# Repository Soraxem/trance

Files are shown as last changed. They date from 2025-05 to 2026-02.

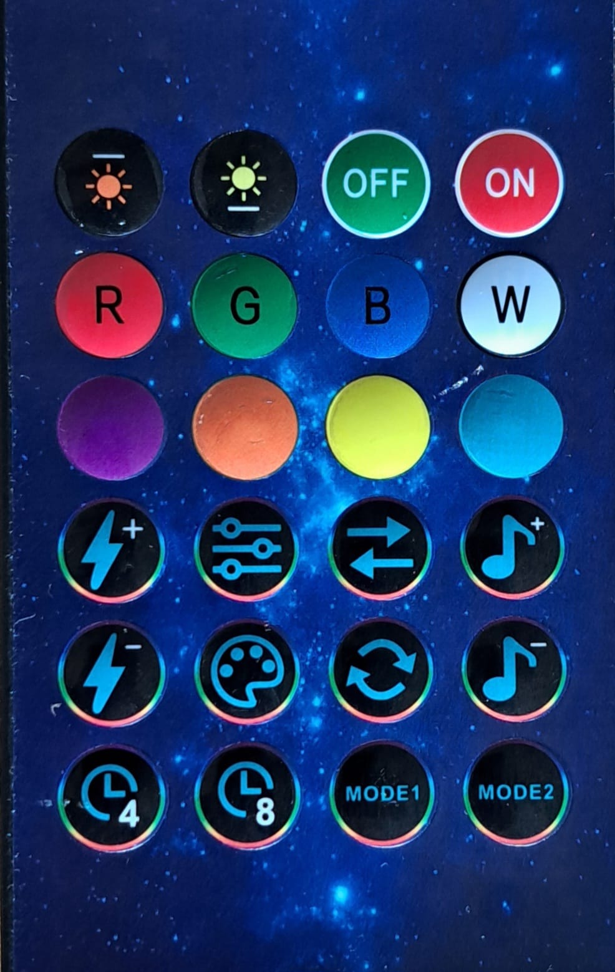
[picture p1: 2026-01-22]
pixel-led/remote-control.jpeg

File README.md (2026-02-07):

[This on Youtube](https://www.youtube.com/playlist?list=PL4cNBOFjqRCpjGmj9xtUntssc8VHCmmZN) | [This on Makertube](https://makertube.net/w/p/su6X6o1RSBtH18CKgF7tRq) | [This on PCBWAY](https://www.pcbway.com/project/member/shareproject/?bmbno=57956445-373F-42)

# Trance

The Trance Device Family are open hardware devices that allow life wireless lighting control via ArtNet 4. These devices mainly have applications in portable, mobile, and flexible lighting solutions.

## Control

Some lighting controllers do not implement ArtNet 4 with udp unicasting. UDP unicasting is essential for wireless lighting, because most WiFi routers ratelimit and occasionally hold back multicasted UDP packets. Unicasted UDP packets do not get ratelimited and are therefore the way to go.

If your controller does not implement UDP multicasting as per ArtNet 4 Specification, you can use my translation layer called artman. [Github Repo here](https://github.com/Soraxem/artman).

## Software

To ensure a flexible and easy software, there is a Arduino library, that implements the communication side of the software. By updating this Library with more Protocols or more reliable networking, we can expand the functionallity of every trance controller, despite hardware differences. This Library also allows for easy hardware development for DIY solutions.

You can find the Library [here on github](https://github.com/Soraxem/trance-library).

## Hardware

This project also features custom hardware that is more compact than just using a ESP32 devboard.

### USB-DMX

This device interfaces with the Eurolite Wireless DMX port on some of the newer Eurolite devices.

### PIXEL-LED

This is a led controller that can interface with the common spi-leds like ws8212. It can directly be plugged in to the usb port of a wall adapter.

## License

This Project is licensed under CERN-OHL-P

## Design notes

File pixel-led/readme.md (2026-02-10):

# Trance PIXEL-LED

## Overview

Pixel LED is simply a Trance model that can control a spi led strip. It is designed to be directly plugged into a wall charger. It features an infrared sensor so it could be integrated with infrared remote controls.

## Sponsorship

[PCBWay](pcbway.com) was so kind to sponsor pcb production of revision 1.0 in development of this device. I quickly wanted to review their services here.

All the pcbs i recieved were up to specification and of good quality. I was suprized an honored to recieve such a sponsoring for such a small project. I admire how PCBWay invests in OpenSource electronics, especially with their project sharing platform.

## Remote

Currently there is only one Remote implemented in the Code. This remote is shipped with these [WS8212 Globe stringlights](aliexpress.com/item/1005009844838768.html), and normally interfaces with that controller.

There are firmware versions with and without the infrared Remote.

## Firmware

The firmware is dependant on multible Librarys, wich are mentioned at the beginning of the firmware source file. Make sure to install the correct versions of these librarys. It also depends on the Trance library, wich is not Published in the Library Manager. To install this library, download the right version from github and put it into your arduino library Folder.

For flashing press the button on the device and plug the USB plug into the computer while keeping the button pressed. By this the microcontroller connects to the computer and expexts a software to be flashed. In arduino select the correct port and configuration, then upload the firmware.

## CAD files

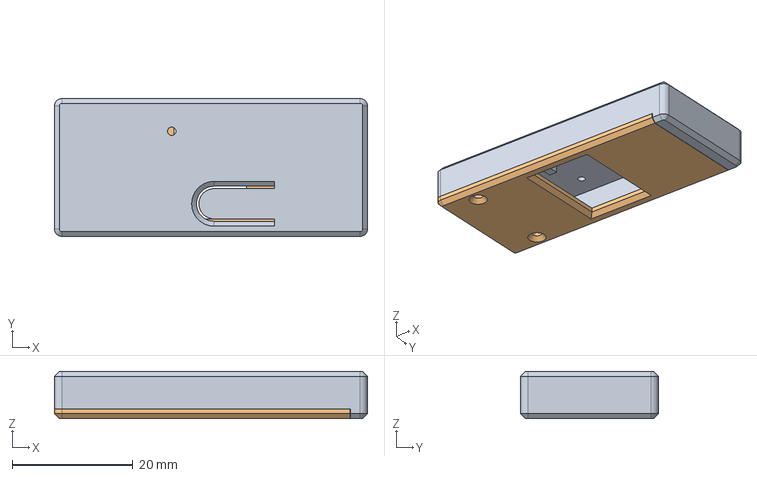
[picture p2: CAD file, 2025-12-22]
usb-dmx/housing/housing.FCStd
51.8 x 22.8 x 7.80 mm
hat
plate

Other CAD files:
usb-dmx/housing/housing.3mf

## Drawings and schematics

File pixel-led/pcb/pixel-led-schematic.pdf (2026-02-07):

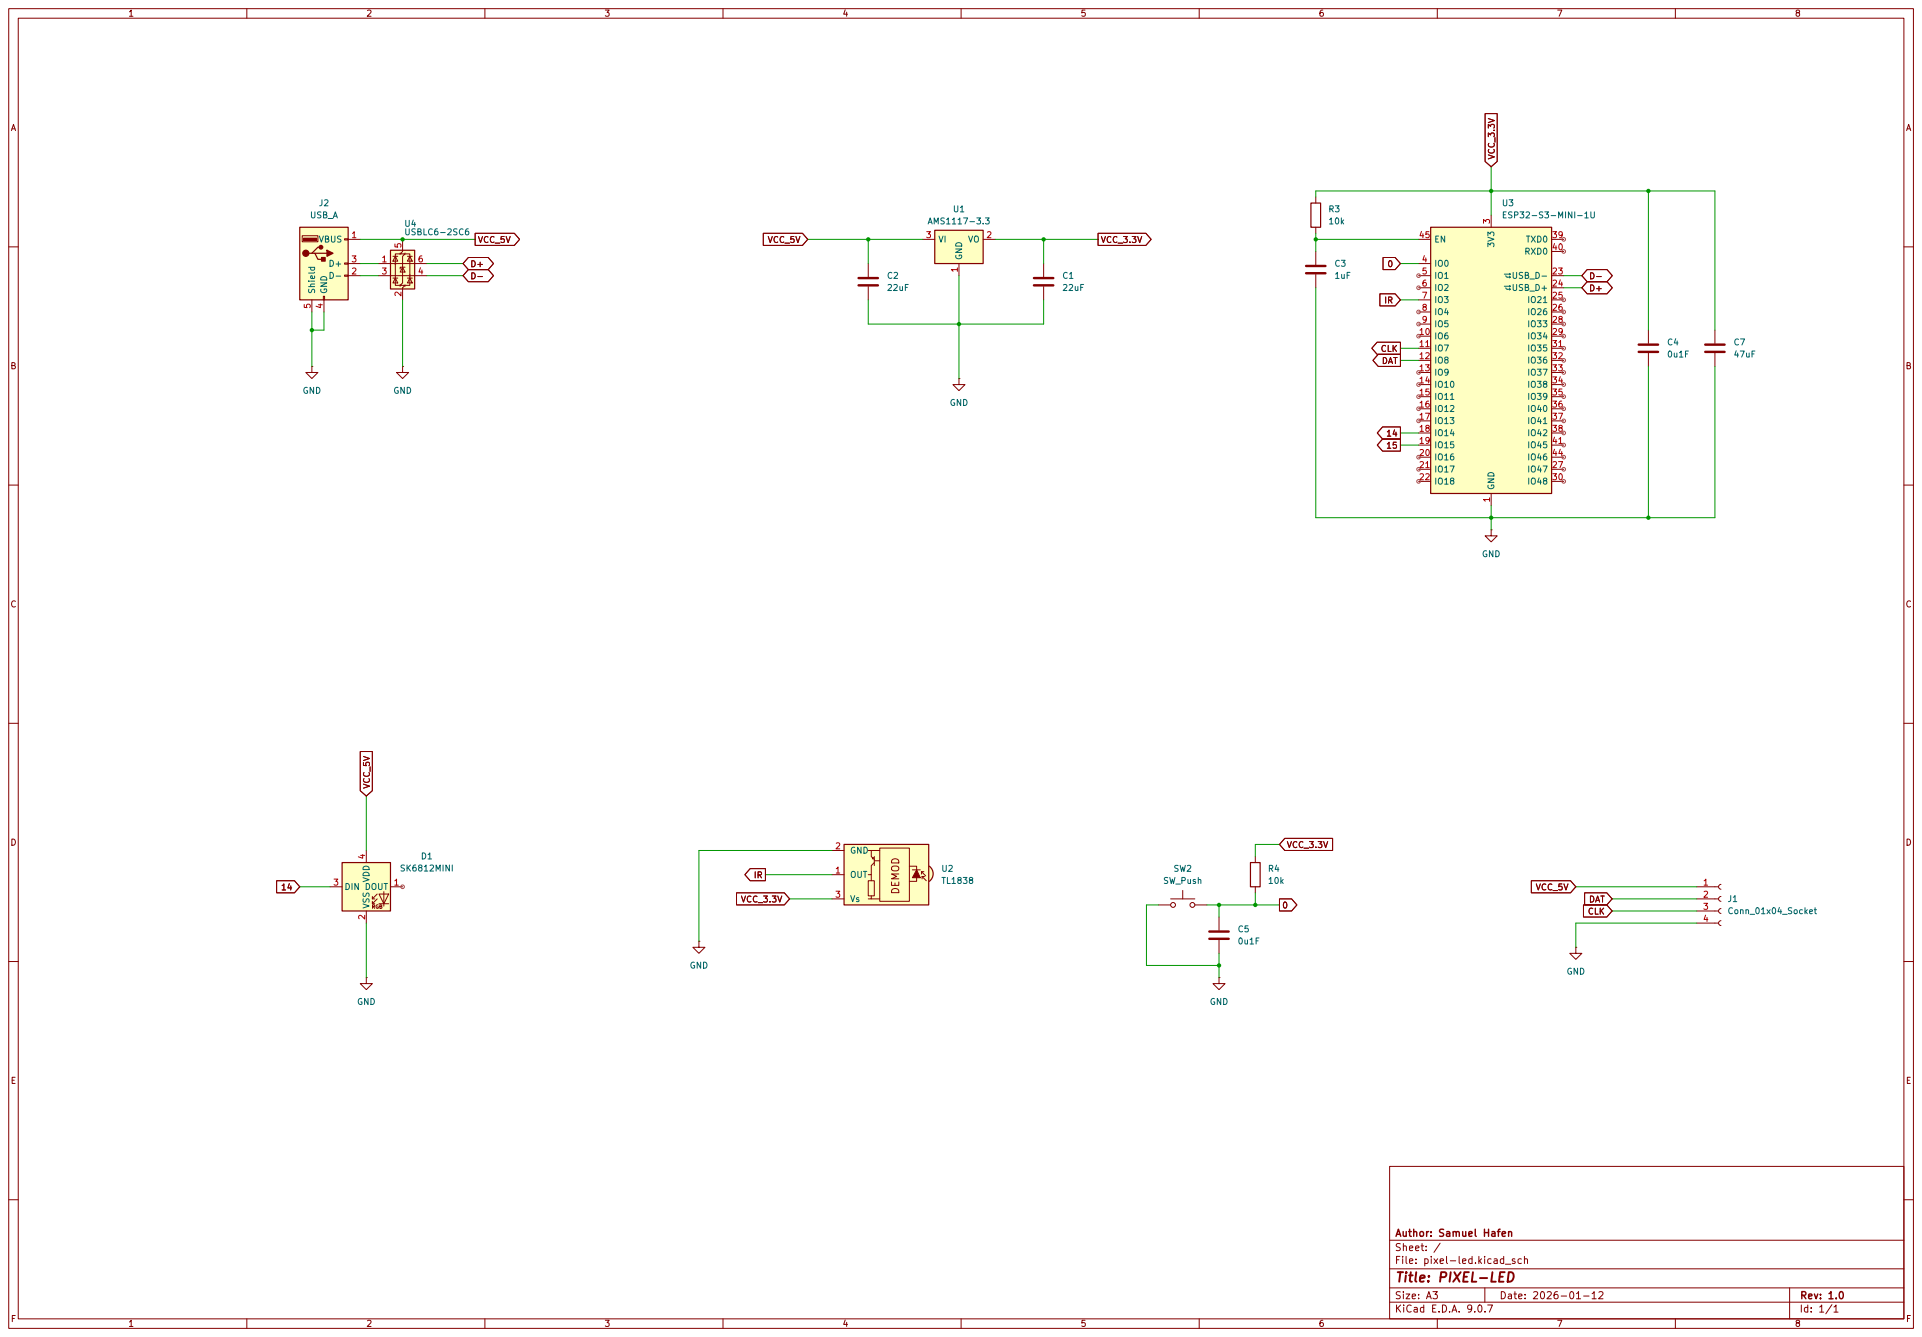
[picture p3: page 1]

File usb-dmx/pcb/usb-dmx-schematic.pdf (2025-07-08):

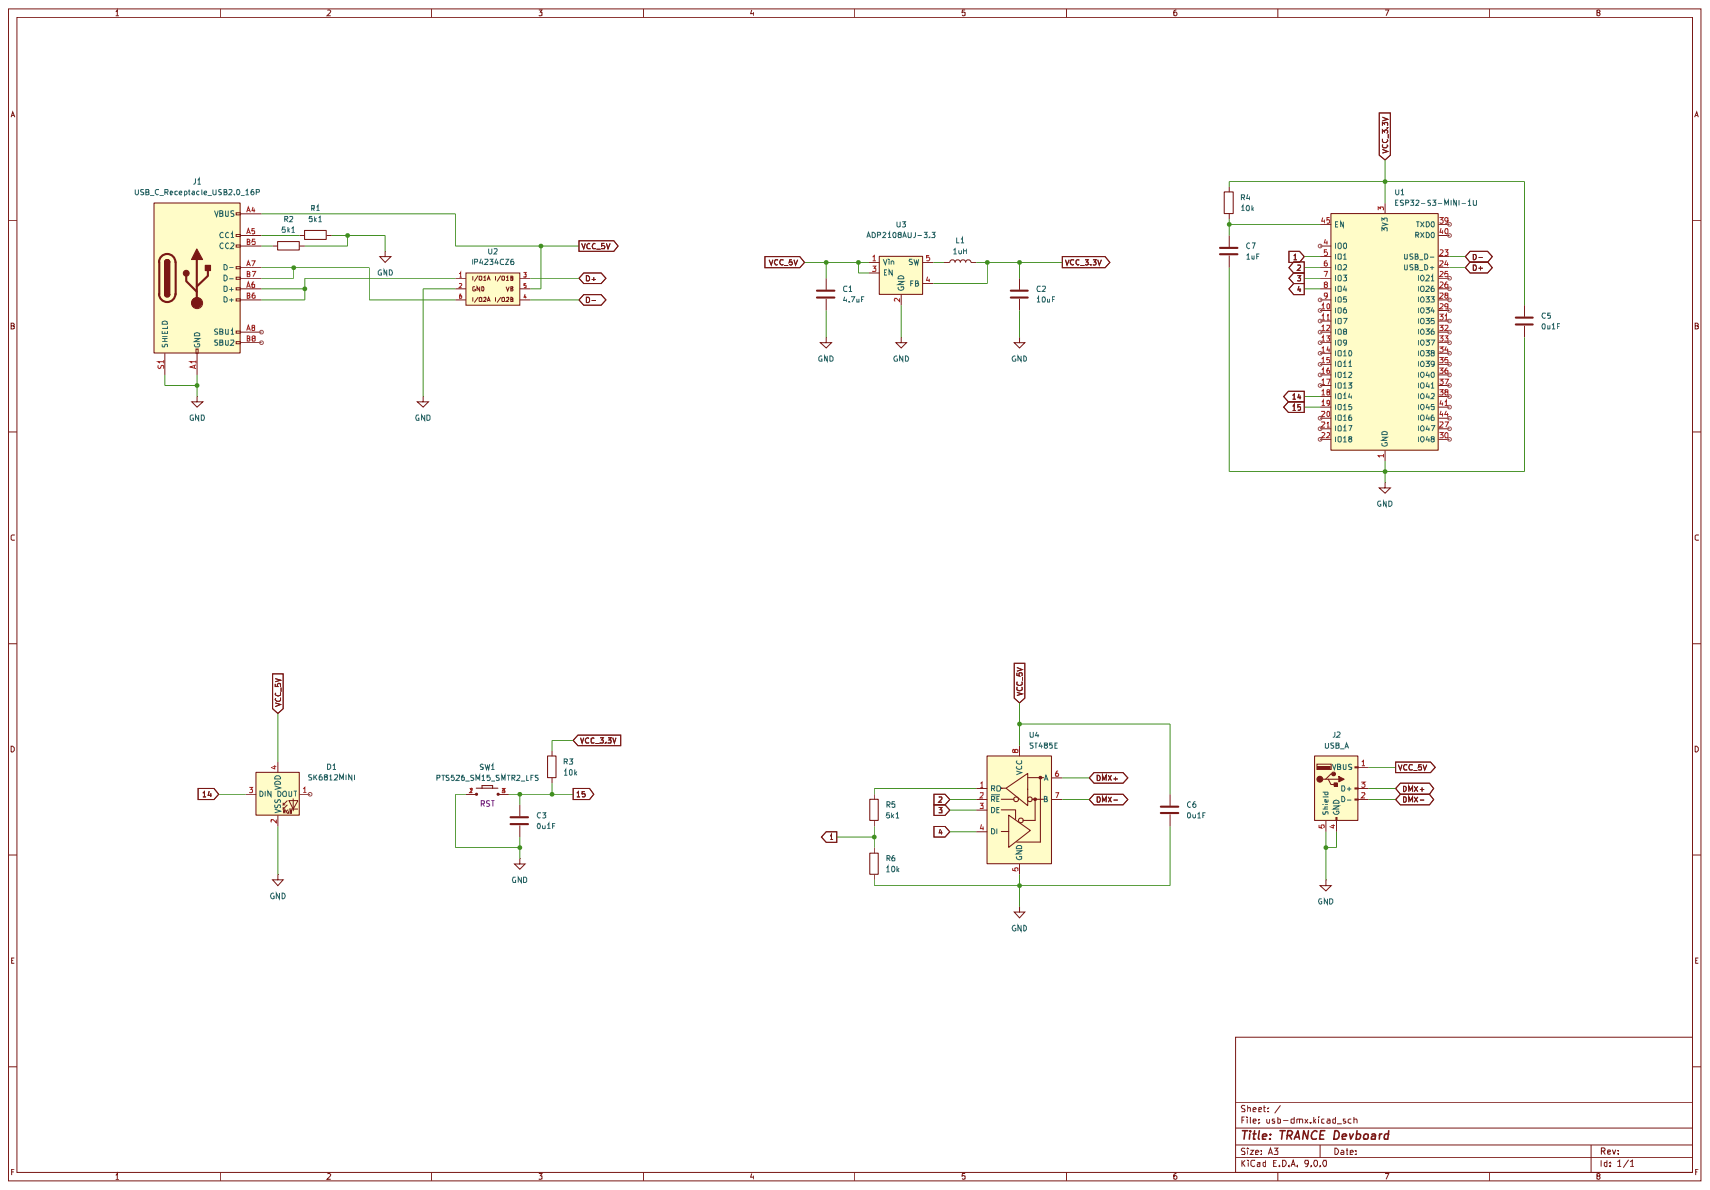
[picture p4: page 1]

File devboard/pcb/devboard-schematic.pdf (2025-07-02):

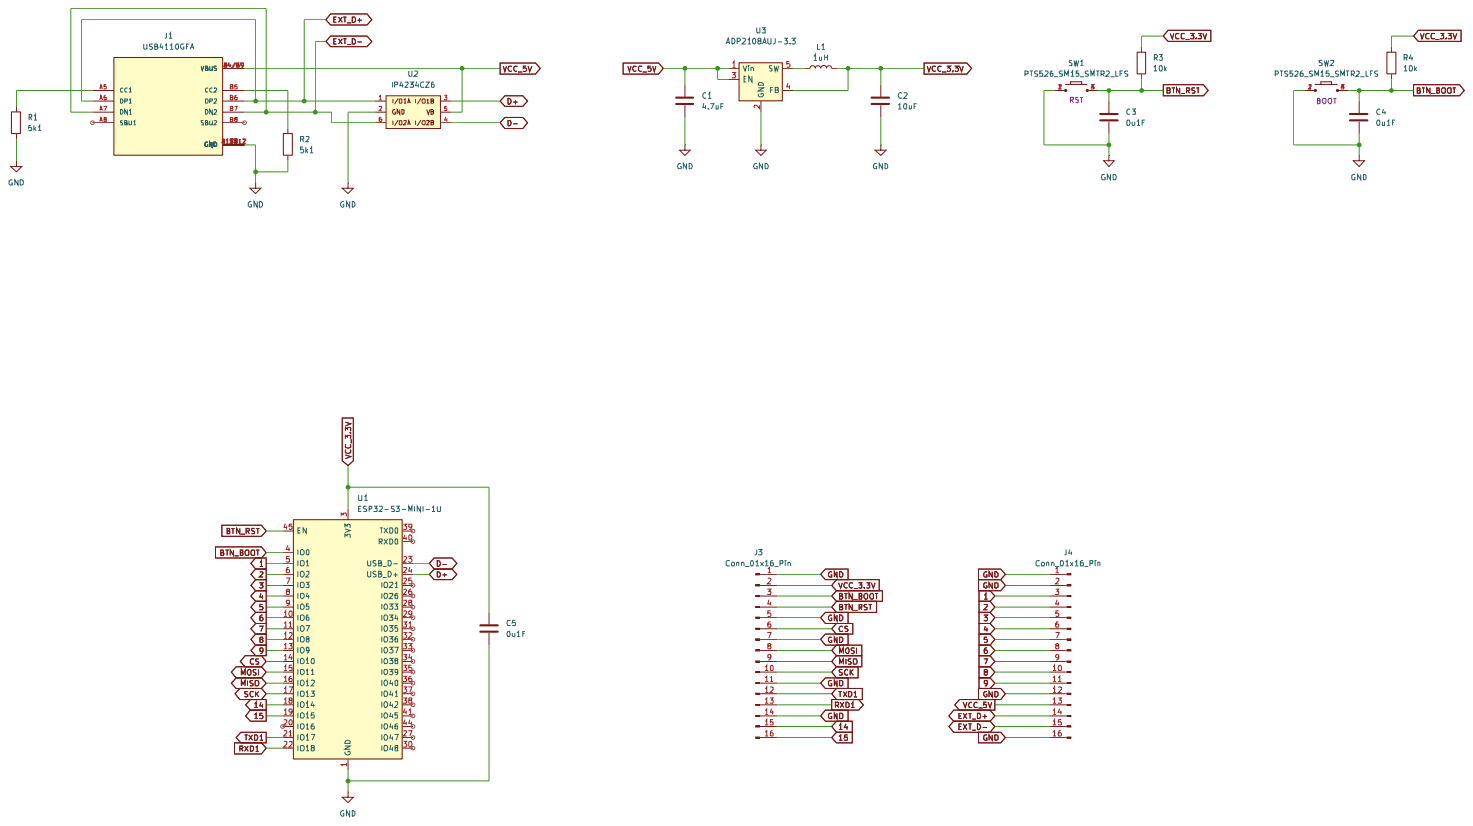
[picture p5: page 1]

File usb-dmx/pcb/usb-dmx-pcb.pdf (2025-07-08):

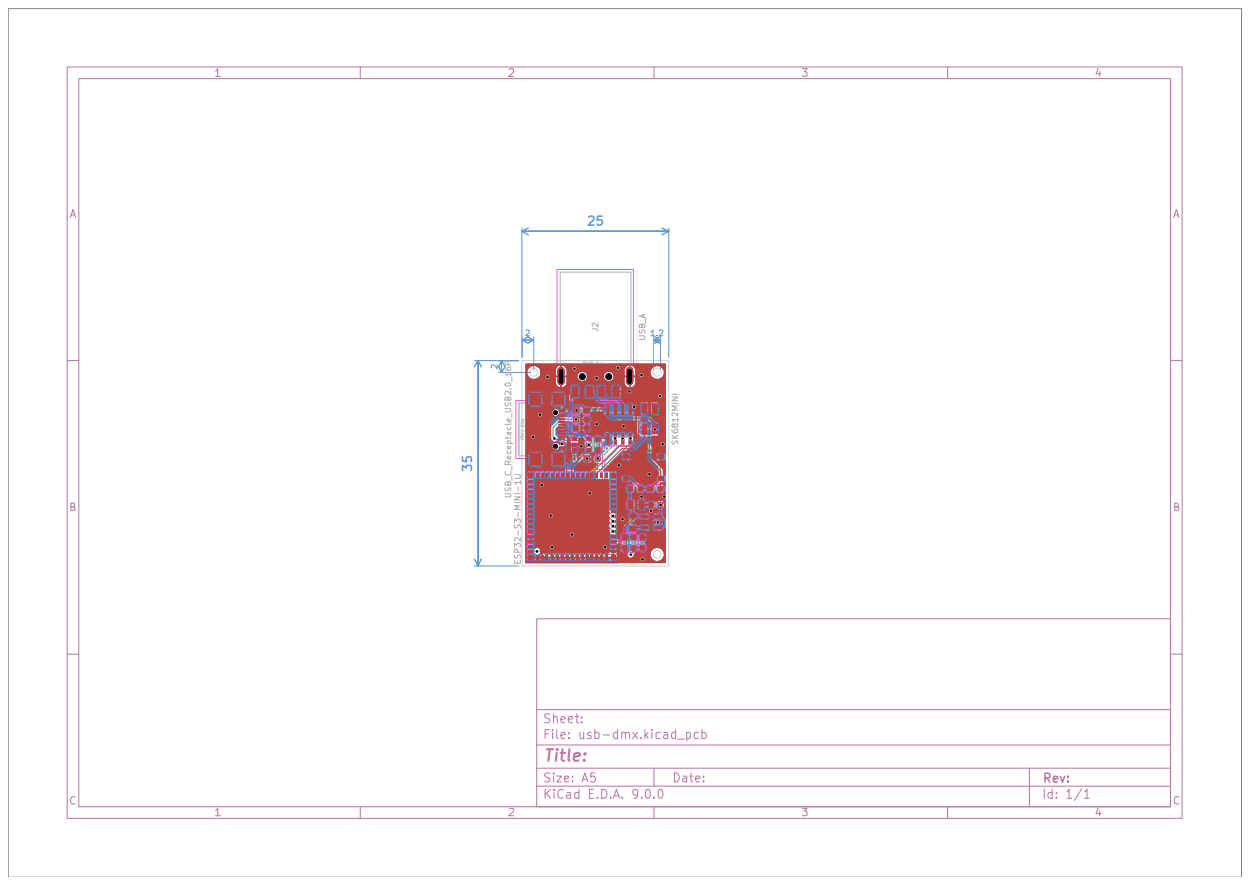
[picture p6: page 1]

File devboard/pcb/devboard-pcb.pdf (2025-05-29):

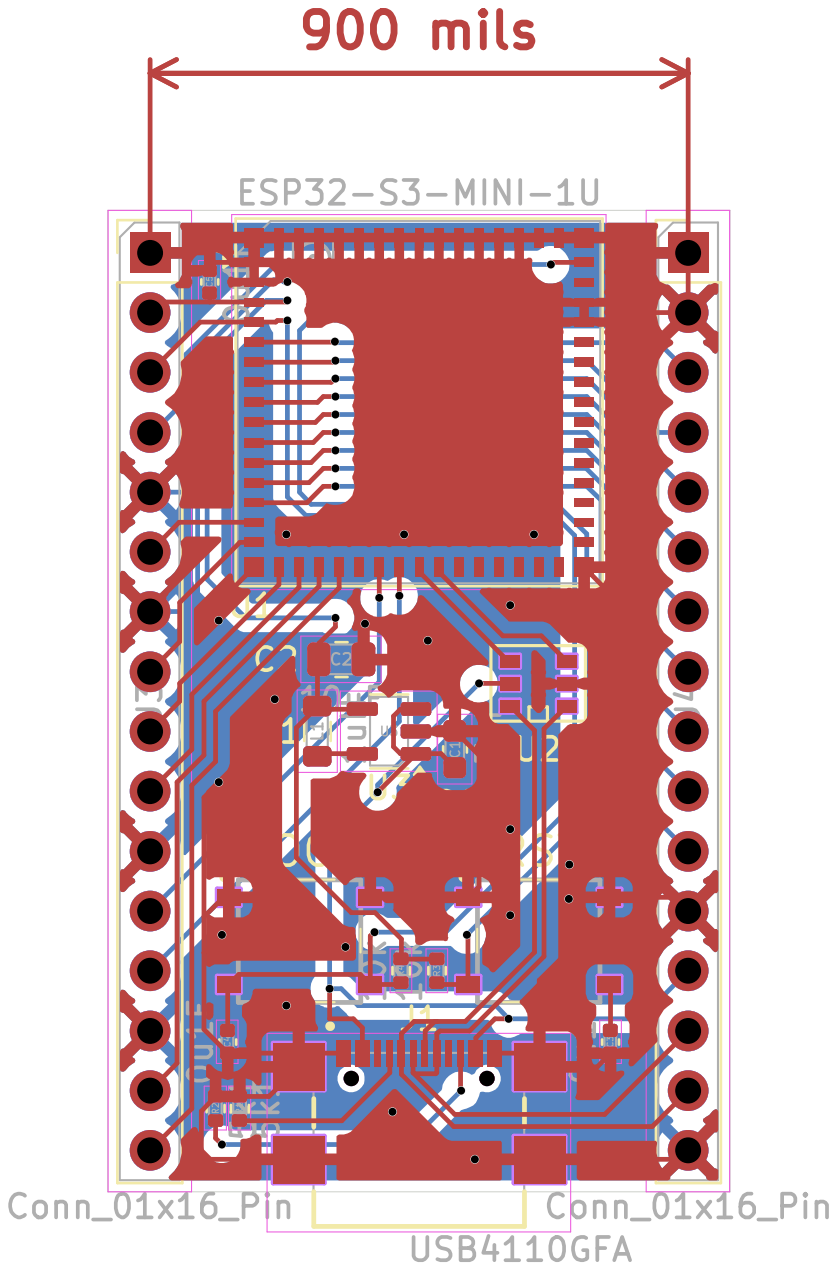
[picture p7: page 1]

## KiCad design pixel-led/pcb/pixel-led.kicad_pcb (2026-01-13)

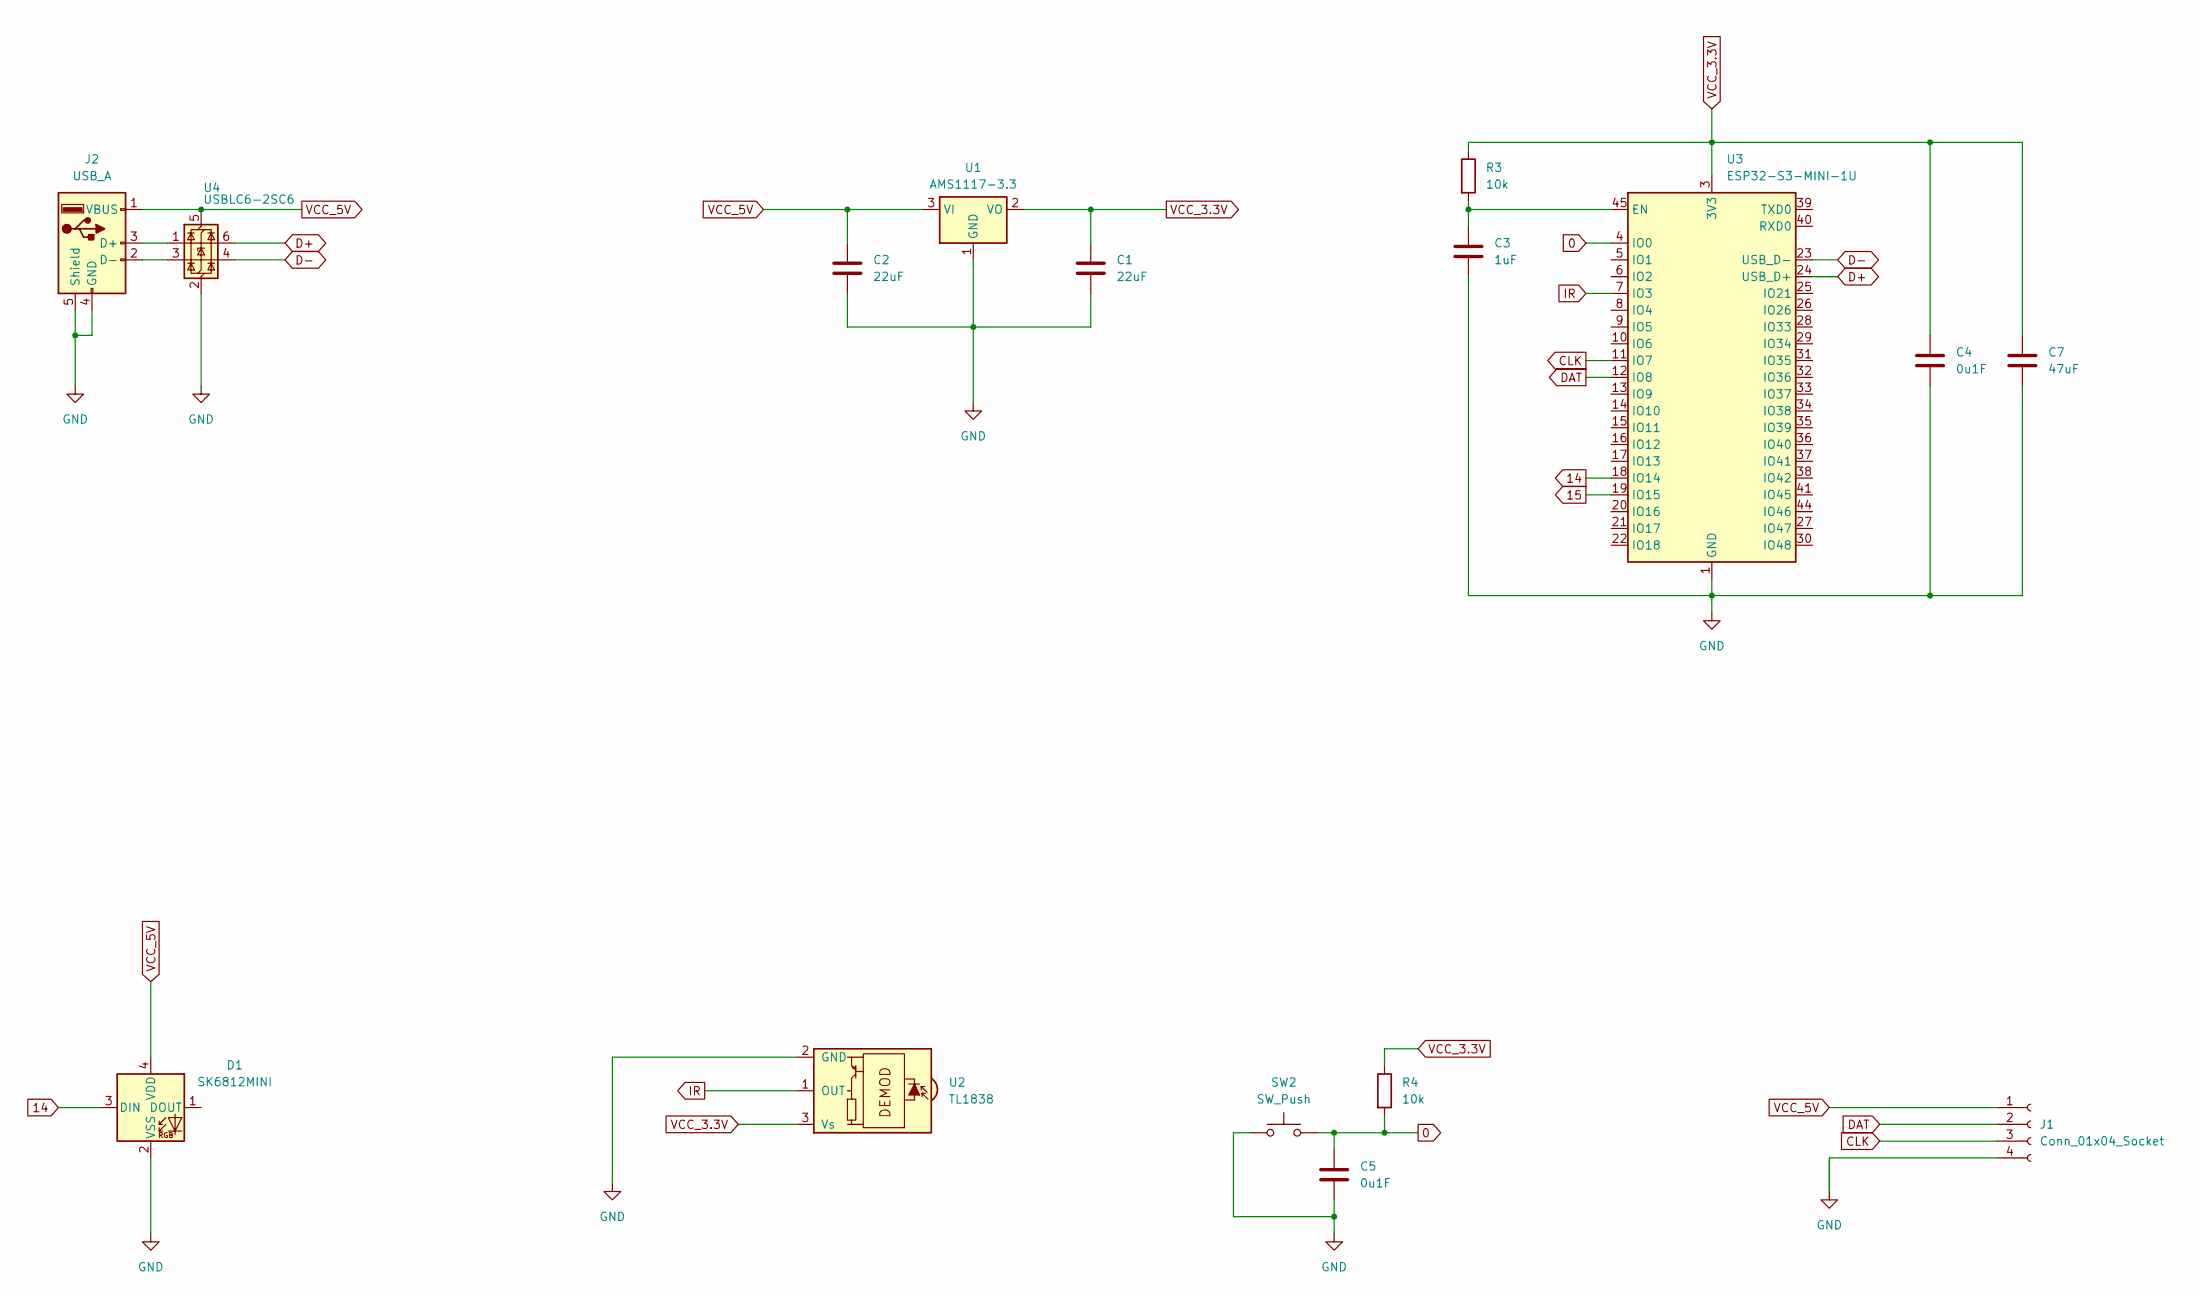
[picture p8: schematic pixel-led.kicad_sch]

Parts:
C1, C2: 22uF; C_0805_2012Metric
C3: 1uF; C_0603_1608Metric_Pad1.08x0.95mm_HandSolder
C4: 0u1F; C_0603_1608Metric_Pad1.08x0.95mm_HandSolder
C5: 0u1F; C_0603_1608Metric
C7: 47uF; C_0805_2012Metric_Pad1.18x1.45mm_HandSolder
D1: SK6812MINI; LED_SK6812MINI_PLCC4_3.5x3.5mm_P1.75mm
J1: Conn_01x04_Socket; PinHeader_1x04_P2.54mm_Vertical
J2: USB_A; USB_A_CNCTech_1001-011-01101_Horizontal
R3: 10k; R_0603_1608Metric_Pad0.98x0.95mm_HandSolder
R4: 10k; R_0603_1608Metric
SW2: SW_Push; SW_Push_1P1T_XKB_TS-1187A
U1: AMS1117-3.3; SOT-223-3_TabPin2
U2: TL1838; TO-92_Inline_Horizontal2
U3: ESP32-S3-MINI-1U; ESP32-S2-MINI-1
U4: USBLC6-2SC6; SOT-23-6

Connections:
0: C5.1, R4.2, SW2.2, U3.4 (IO0)
14: D1.3 (DIN), U3.18 (IO14)
15: U3.19 (IO15)
CLK: J1.3, U3.11 (IO7)
D+: U3.24 (USB_D+), U4.6 (I/O1)
D-: U3.23 (USB_D-), U4.4 (I/O2)
DAT: J1.2, U3.12 (IO8)
GND: C1.2, C2.2, C3.2, C4.2, C5.2, C7.2, D1.2 (VSS), J1.4, J2.4 (GND), J2.5 (Shield), SW2.1, U1.1 (GND), U2.2 (GND), U3.1 (GND), U3.2 (GND), U3.42 (GND), U3.43 (GND), U3.46 (GND), U3.47 (GND), U3.48 (GND), U3.49 (GND), U3.50 (GND), U3.51 (GND), U3.52 (GND), U3.53 (GND), U3.54 (GND), U3.55 (GND), U3.56 (GND), U3.57 (GND), U3.58 (GND), U3.59 (GND), U3.60 (GND), U3.61 (GND), U3.62 (GND), U3.63 (GND), U3.64 (GND), U3.65 (GND), U4.2 (GND)
IR: U2.1 (OUT), U3.7 (IO3)
unnamed: J2.3 (D+), U4.1 (I/O1)
unnamed: J2.2 (D-), U4.3 (I/O2)
unnamed: C3.1, R3.2, U3.45 (EN)
VCC_3.3V: C1.1, C4.1, C7.1, R3.1, R4.1, U1.2 (VO), U2.3 (Vs), U3.3 (3V3)
VCC_5V: C2.1, D1.4 (VDD), J1.1, J2.1 (VBUS), U1.3 (VI), U4.5 (VBUS)

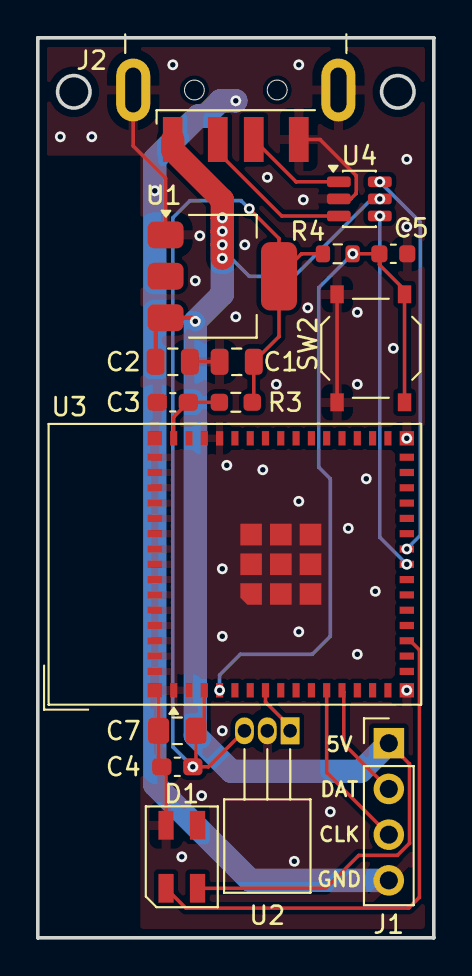
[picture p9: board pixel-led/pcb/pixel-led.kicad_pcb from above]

Board: 2 copper layers, 22.0 x 50.0 mm, 16 parts (0 on the bottom side), 13 nets.

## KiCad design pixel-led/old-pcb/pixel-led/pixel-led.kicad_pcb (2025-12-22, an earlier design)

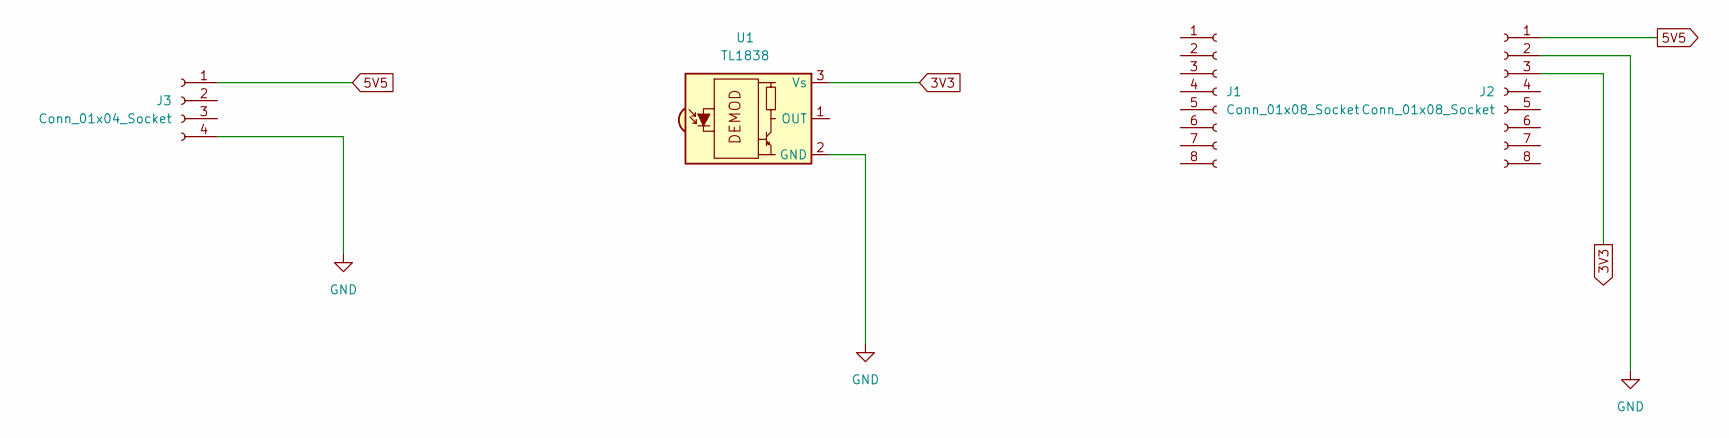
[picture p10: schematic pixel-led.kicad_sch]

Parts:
J1, J2: Conn_01x08_Socket; PinHeader_1x08_P2.54mm_Vertical
J3: Conn_01x04_Socket; PinHeader_1x04_P2.54mm_Vertical
U1: TL1838; Vishay_MINICAST-3Pin

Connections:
3V3: J2.3, U1.3 (Vs)
5V5: J2.1, J3.1
GND: J2.2, J3.4, U1.2 (GND)

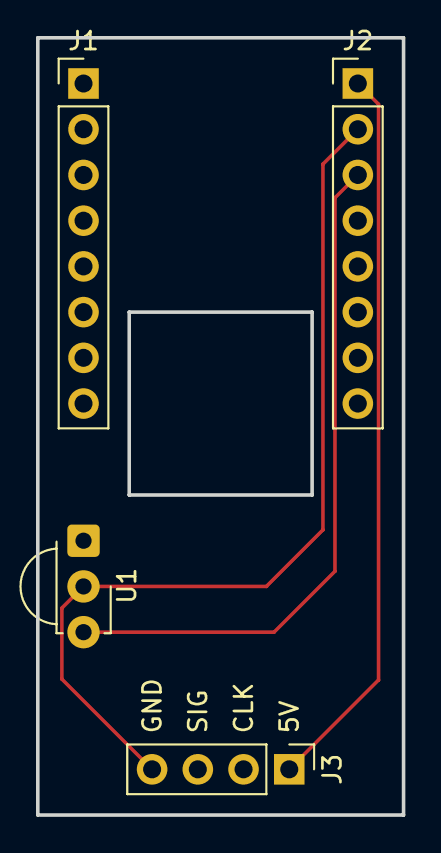
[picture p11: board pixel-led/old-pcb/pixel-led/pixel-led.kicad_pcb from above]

Board: 2 copper layers, 20.3 x 43.2 mm, 4 parts (0 on the bottom side), 3 nets.

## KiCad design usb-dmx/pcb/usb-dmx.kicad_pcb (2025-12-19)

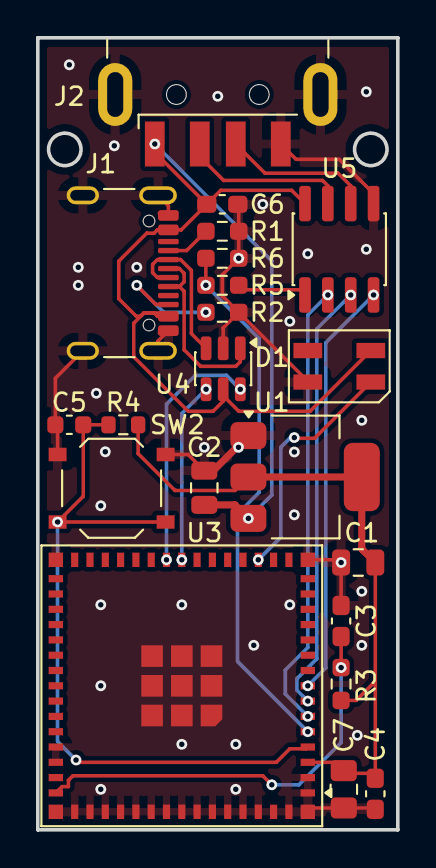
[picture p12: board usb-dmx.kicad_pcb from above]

Board: 2 copper layers, 20.0 x 44.0 mm, 21 parts (0 on the bottom side), 19 nets.

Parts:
C1, C2: 22uF; C_0805_2012Metric
C3: 1uF; C_0603_1608Metric_Pad1.08x0.95mm_HandSolder
C4, C6: 0u1F; C_0603_1608Metric_Pad1.08x0.95mm_HandSolder
C5: 0u1F; C_0603_1608Metric
C7: 47uF; C_0805_2012Metric_Pad1.18x1.45mm_HandSolder
D1: SK6812MINI; LED_SK6812MINI_PLCC4_3.5x3.5mm_P1.75mm
J1: USB_C_Receptacle_USB2.0_16P; USB_C_Receptacle_GCT_USB4105-xx-A_16P_TopMnt_Horizontal
J2: USB_A; USB_A_CNCTech_1001-011-01101_Horizontal
R1, R2, R5: 5k1; R_0603_1608Metric_Pad0.98x0.95mm_HandSolder
R3, R6: 10k; R_0603_1608Metric_Pad0.98x0.95mm_HandSolder
R4: 10k; R_0603_1608Metric
SW2: SW_Push; SW_Push_1P1T_XKB_TS-1187A
U1: AMS1117-3.3; SOT-223-3_TabPin2
U3: ESP32-S3-MINI-1U; ESP32-S2-MINI-1U
U4: USBLC6-2SC6; SOT-23-6
U5: MAX485E; SOP-8_3.76x4.96mm_P1.27mm

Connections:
0: C5.1, R4.2, SW2.2, U3.4 (IO0)
1: R5.1, R6.1, U3.5 (IO1)
2: U3.6 (IO2), U5.2 (~RE)
3: U3.7 (IO3), U5.3 (DE)
4: U3.8 (IO4), U5.4 (DI)
14: D1.3 (DIN), U3.18 (IO14)
D+: U3.24 (USB_D+), U4.6 (I/O1)
D-: U3.23 (USB_D-), U4.4 (I/O2)
DMX+: J2.3 (D+), U5.6 (A)
DMX-: J2.2 (D-), U5.7 (B)
GND: C1.2, C2.2, C3.2, C4.2, C5.2, C6.2, C7.2, D1.2 (VSS), J1.A1 (GND), J1.A12 (GND), J1.B1 (GND), J1.B12 (GND), J1.S1 (SHIELD), J2.4 (GND), J2.5 (Shield), R1.2, R2.2, R6.2, SW2.1, U1.1 (GND), U3.1 (GND), U3.2 (GND), U3.42 (GND), U3.43 (GND), U3.46 (GND), U3.47 (GND), U3.48 (GND), U3.49 (GND), U3.50 (GND), U3.51 (GND), U3.52 (GND), U3.53 (GND), U3.54 (GND), U3.55 (GND), U3.56 (GND), U3.57 (GND), U3.58 (GND), U3.59 (GND), U3.60 (GND), U3.61 (GND), U3.62 (GND), U3.63 (GND), U3.64 (GND), U3.65 (GND), U4.2 (GND), U5.5 (GND)
unnamed: J1.A5 (CC1), R1.1
unnamed: J1.B5 (CC2), R2.1
unnamed: J1.A6 (D+), J1.B6 (D+), U4.1 (I/O1)
unnamed: J1.A7 (D-), J1.B7 (D-), U4.3 (I/O2)
unnamed: C3.1, R3.2, U3.45 (EN)
unnamed: R5.2, U5.1 (RO)
VCC_3.3V: C1.1, C4.1, C7.1, R3.1, R4.1, U1.2 (VO), U3.3 (3V3)
VCC_5V: C2.1, C6.1, D1.4 (VDD), J1.A4 (VBUS), J1.A9 (VBUS), J1.B4 (VBUS), J1.B9 (VBUS), J2.1 (VBUS), U1.3 (VI), U4.5 (VBUS), U5.8 (VCC)

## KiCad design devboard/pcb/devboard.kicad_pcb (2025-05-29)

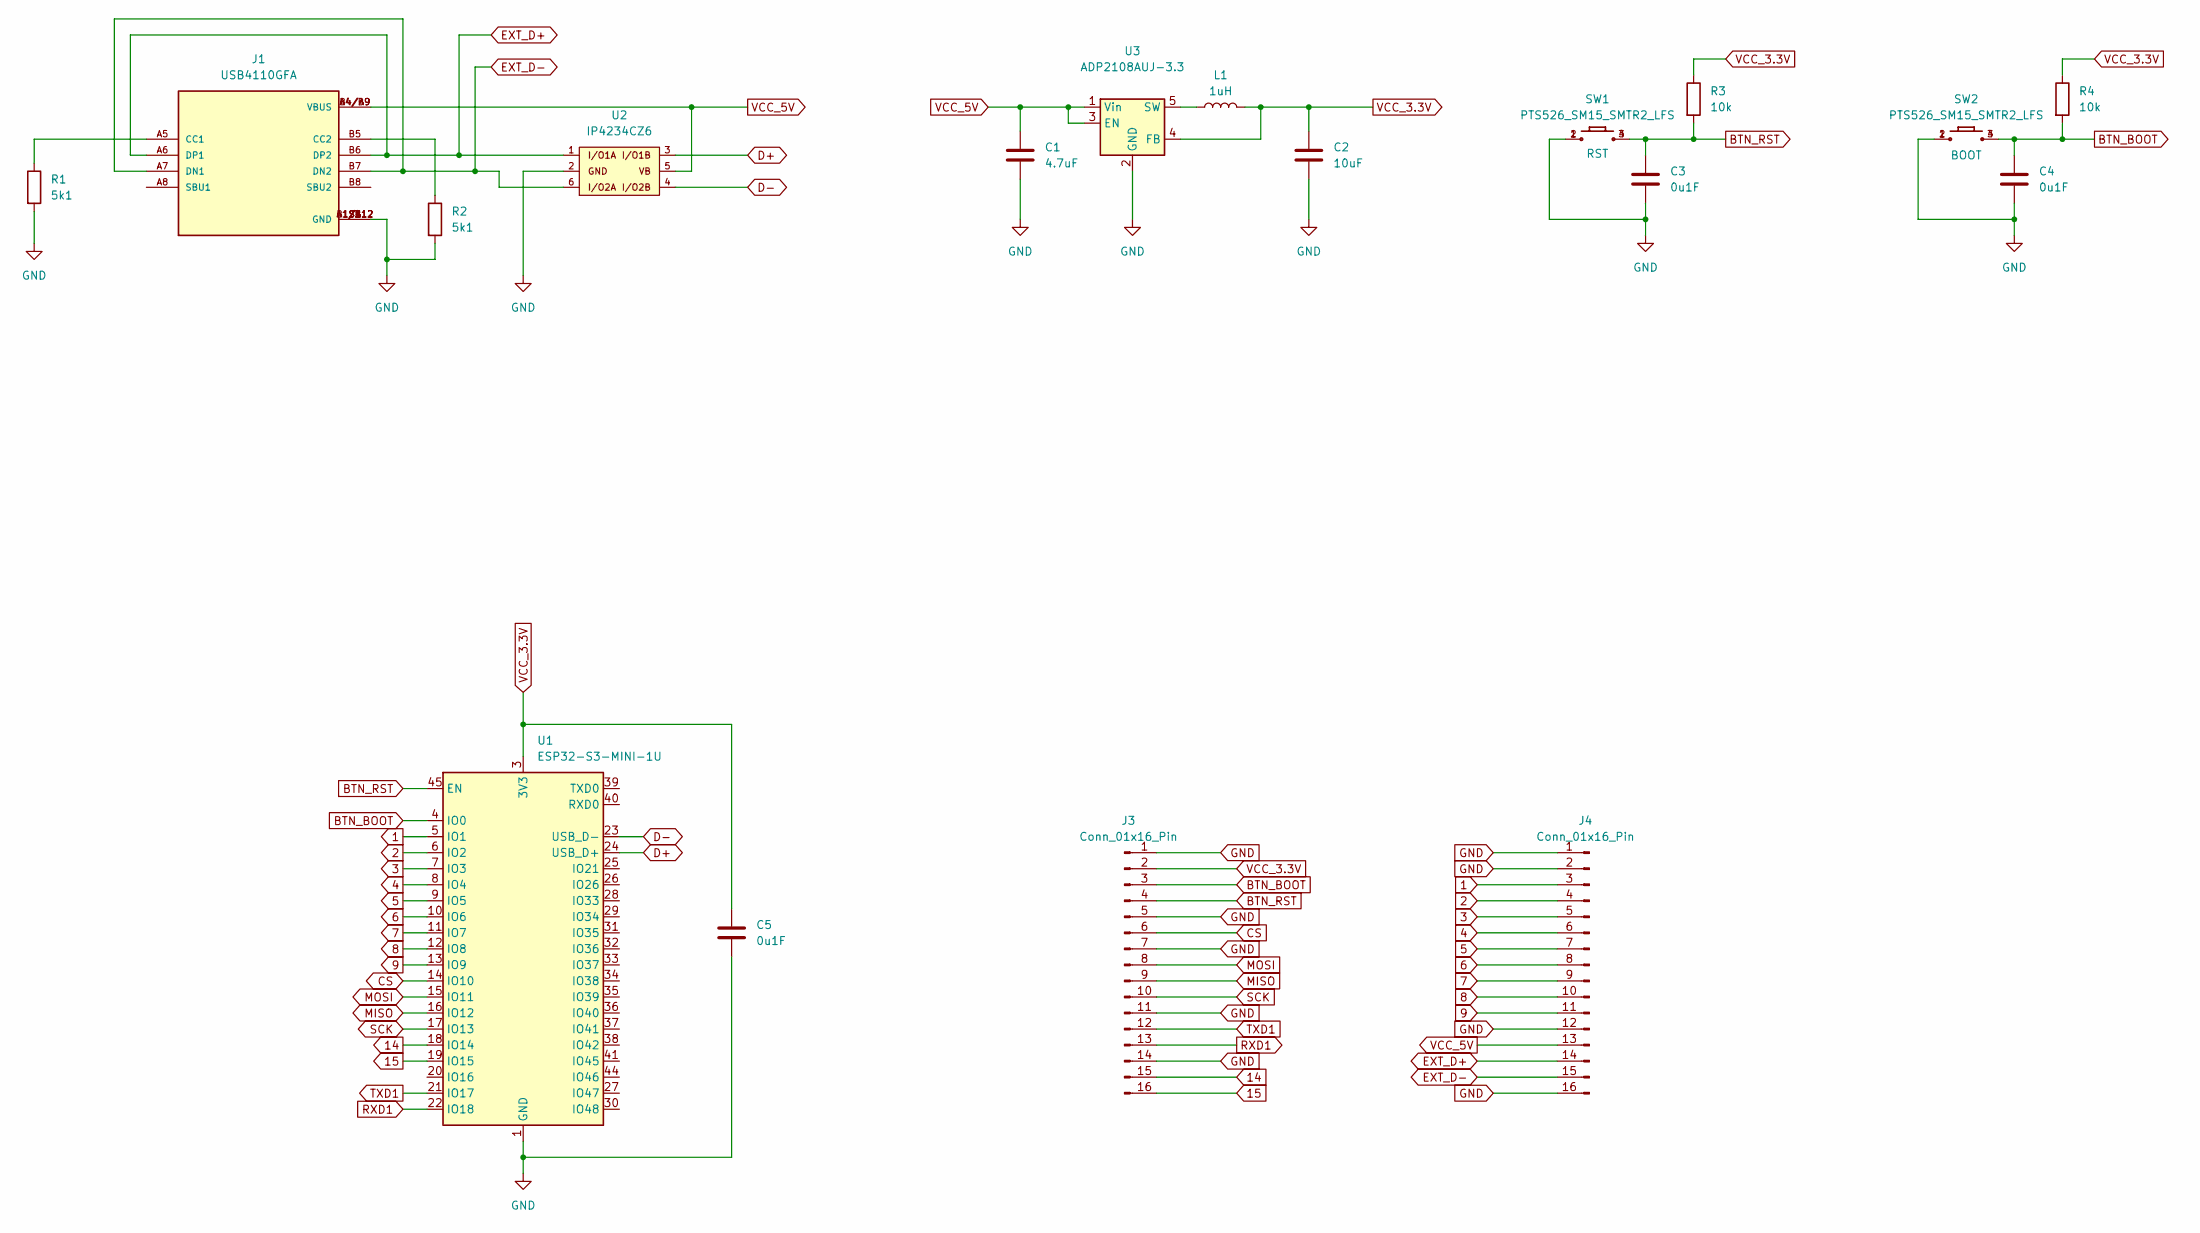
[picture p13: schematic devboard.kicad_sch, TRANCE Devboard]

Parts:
C1: 4.7uF; C_0603_1608Metric; MOUSER_PART_NUMBER 187-CL10A475KO8NNNC
C2: 10uF; C_0805_2012Metric; MOUSER_PART_NUMBER 187-CL21A106KOQNNNF
C3, C4, C5: 0u1F; C_0402_1005Metric; MOUSER_PART_NUMBER 187-CL05F104ZO5NNND
J1: USB4110GFA; GCT_USB4110GFA; MOUSER_PART_NUMBER 640-USB4110-GF-A; DigiKey_Part_Number 2073-USB4110-GF-A-2-ND
J3, J4: Conn_01x16_Pin; PinHeader_1x16_P2.54mm_Vertical; MOUSER_PART_NUMBER 200-TSW11607TS
L1: 1uH; L_0805_2012Metric; MOUSER_PART_NUMBER 81-LQM21PN1R0MC0D
R1, R2: 5k1; R_0402_1005Metric; MOUSER_PART_NUMBER 71-CRCW0402-5.1K-E3
R3, R4: 10k; R_0402_1005Metric; MOUSER_PART_NUMBER 71-CRCW0402-10K-E3
SW1, SW2: PTS526_SM15_SMTR2_LFS; PTS526SM15SMTR2LFS; MOUSER_PART_NUMBER 611-PTS526SM15SMTR2L
U1: ESP32-S3-MINI-1U; ESP32-S2-MINI-1U; MOUSER_PART_NUMBER 356-ESP32S3MINI1UN8
U2: IP4234CZ6; IP4234CZ6_SOT-457-6; MOUSER_PART_NUMBER 771-IP4234CZ6
U3: ADP2108AUJ-3.3; TSOT-23-5; MOUSER_PART_NUMBER 584-ADP2108AUJZ3.3R7

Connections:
1: J4.3, U1.5 (IO1)
2: J4.4, U1.6 (IO2)
3: J4.5, U1.7 (IO3)
4: J4.6, U1.8 (IO4)
5: J4.7, U1.9 (IO5)
6: J4.8, U1.10 (IO6)
7: J4.9, U1.11 (IO7)
8: J4.10, U1.12 (IO8)
9: J4.11, U1.13 (IO9)
14: J3.15, U1.18 (IO14)
15: J3.16, U1.19 (IO15)
BTN_BOOT: C4.1, J3.3, R4.2, SW2.3, SW2.4, U1.4 (IO0)
BTN_RST: C3.1, J3.4, R3.2, SW1.3, SW1.4, U1.45 (EN)
CS: J3.6, U1.14 (IO10)
D+: U1.24 (USB_D+), U2.3
D-: U1.23 (USB_D-), U2.4
EXT_D+: J1.A6 (DP1), J1.B6 (DP2), J4.14, U2.1
EXT_D-: J1.A7 (DN1), J1.B7 (DN2), J4.15, U2.6
GND: C1.2, C2.2, C3.2, C4.2, C5.2, J1.A1/B12 (GND), J1.B1/A12 (GND), J1.S1 (GND), J1.S2 (GND), J1.S3 (GND), J1.S4 (GND), J3.1, J3.5, J3.7, J3.11, J3.14, J4.1, J4.2, J4.12, J4.16, R1.2, R2.2, SW1.1, SW1.2, SW2.1, SW2.2, U1.1 (GND), U1.2 (GND), U1.42 (GND), U1.43 (GND), U1.46 (GND), U1.47 (GND), U1.48 (GND), U1.49 (GND), U1.50 (GND), U1.51 (GND), U1.52 (GND), U1.53 (GND), U1.54 (GND), U1.55 (GND), U1.56 (GND), U1.57 (GND), U1.58 (GND), U1.59 (GND), U1.60 (GND), U1.61 (GND), U1.62 (GND), U1.63 (GND), U1.64 (GND), U1.65 (GND), U2.2, U3.2 (GND)
MISO: J3.9, U1.16 (IO12)
MOSI: J3.8, U1.15 (IO11)
unnamed: J1.A5 (CC1), R1.1
unnamed: J1.B5 (CC2), R2.1
unnamed: L1.1, U3.5 (SW)
RXD1: J3.13, U1.22 (IO18)
SCK: J3.10, U1.17 (IO13)
TXD1: J3.12, U1.21 (IO17)
VCC_3.3V: C2.1, C5.1, J3.2, L1.2, R3.1, R4.1, U1.3 (3V3), U3.4 (FB)
VCC_5V: C1.1, J1.A4/B9 (VBUS), J1.B4/A9 (VBUS), J4.13, U2.5, U3.1 (Vin), U3.3 (EN)

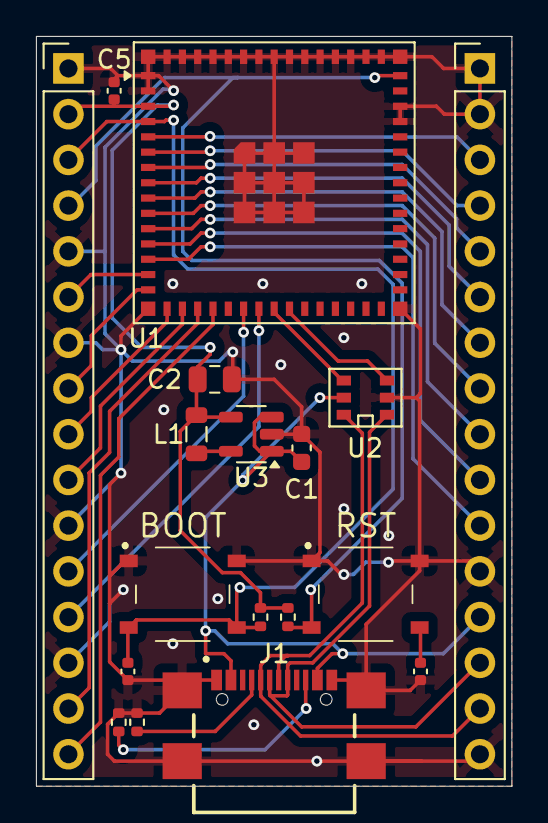
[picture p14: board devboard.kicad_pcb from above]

Board: 2 copper layers, 26.4 x 41.7 mm, 18 parts (0 on the bottom side), 29 nets.

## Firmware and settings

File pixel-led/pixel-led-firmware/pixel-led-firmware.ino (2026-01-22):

/*
  Device:         Trance PIXEL-LED Prototype
  Board:          ESP32C3 Dev Module
  Board Library:  esp32 v3.0.4
  Dependencies:   trance v0.0.3, ArtNet v0.9.2, FastLED v3.10.3, IRremote v4.5.0
  Author:         Samuel Hafen
*/

#include <Arduino.h>
#include <Trance.h>
#include <FastLED.h>
#include <IRremote.hpp>

// Prototype because compiler sad
void callback(uint8_t test[]);
void handle_infrared();
void handle_modes();

#define NUM_LEDS 50

#define DATA_PIN 4
CRGB leds[NUM_LEDS];


namespace Mode {
  enum Mode {
    TRANCE_MODE,
    BLACK_OUT,
    PROGRAM,
    MANUAL,
  };
}

namespace Program {
  enum program {
    RAINBOW,
    ABSTRACT,
    FIRE,
    OCEAN,
    LINE,
    COUNT
  };

  program current = RAINBOW;

  uint8_t animation_state = 0;
  uint8_t animation_speed = 15;

  int last_millis = 0;

  void next() {
    // 1. Convert to int and increment
    // 2. Use modulo to wrap around (3 % 3 = 0)
    // 3. Cast back to the 'program' type
    current = static_cast<program>((current + 1) % COUNT);
  }
}

namespace Manual {
  enum color {
    RED,
    GREEN,
    BLUE,
  };

  uint8_t red_level = 0;
  uint8_t green_level = 0;
  uint8_t blue_level = 0;

  color selected;
}

// create mode variable with standart value TRANCE_MODE
Mode::Mode mode = Mode::TRANCE_MODE;


void setup() {
  // setup Trance
  delay(1000);

  Trance.begin(150, callback, 9);

  FastLED.addLeds<WS2812, DATA_PIN, RGB>(leds, NUM_LEDS);
  FastLED.setBrightness(255);

  IrReceiver.begin(3, false);

  Serial.begin(115200);
}

void loop() {
  Trance.handle();
  FastLED.show();
  handle_infrared();
  handle_modes();
  delay(5);  //allow the cpu to switch to other tasks
}

// recieves data from Trance
void callback(uint8_t channels[]) {
  if (mode == Mode::TRANCE_MODE) {
    for (int i = 0; i < NUM_LEDS; i++) {
      leds[i] = CRGB(channels[i*3], channels[i*3+1], channels[i*3+2]);
    }
  }
}

// Eurolie IR-7 Remote Control Commands
// Values are arranged in a Table as the buttons are arranged
namespace IR_7 {
enum Key {
  BLACK_OUT = 0,  AUTO = 1,     SOUND = 2,
  STROBE = 3,     SPEED = 4,    SENSITIVITY = 5,
  DMX = 6,        MANUAL = 7,   FADE = 8,

  RED = 9,        GREEN = 10,   BLUE = 11,

  PLUS = 12,      ZERO = 13,    MIUNS = 14,
  ONE = 15,       TWO = 16,     THREE = 17,
  FOUR = 18,      FIVE = 19,    SIX = 20,
  SEVEN = 21,     EIGHT = 22,   NINE = 23,
};
}

namespace Remote {
  enum Key {
    // Row 1 (Top Controls)
    BRIGHT = 0, 
    DIM = 1, 
    OFF = 2, 
    ON = 3,

    // Row 2 (Primary Colors)
    RED = 4, 
    GREEN = 5, 
    BLUE = 6, 
    WHITE = 7,

    // Row 3 (Secondary Colors)
    PURPLE = 8, 
    ORANGE = 9, 
    YELLOW = 10, 
    CYAN = 11,

    // Row 4 (Effects & Music)
    SPEED_UP = 12,    // Lightning icon with +
    SETTINGS = 13,    // Sliders/EQ icon
    SWITCH_DIR = 14,  // Left/Right arrows
    MUSIC_UP = 15,    // Music note with +

    // Row 5 (Adjustments)
    SPEED_DOWN = 16,  // Lightning icon with -
    PALETTE = 17,     // Paint palette icon
    CYCLE = 18,       // Circular recycle arrows
    MUSIC_DOWN = 19,  // Music note with -

    // Row 6 (Timers & Modes)
    TIMER_4H = 20,    // Clock with 4
    TIMER_8H = 21,    // Clock with 8
    MODE_1 = 22,
    MODE_2 = 23
  };
}

void handle_infrared() {
  if (IrReceiver.decode()) {
    Serial.print("Got Infrared! command: ");
    Serial.println(IrReceiver.decodedIRData.command);

    bool repeat = IrReceiver.decodedIRData.flags & IRDATA_FLAGS_IS_REPEAT;

    // Check for Eurolie IR-7 Remote Control
    if (IrReceiver.decodedIRData.address == 61706) {
      switch (IrReceiver.decodedIRData.command) {
        case IR_7::BLACK_OUT:
          mode = Mode::BLACK_OUT;
          break;
        case IR_7::AUTO:
          mode = Mode::PROGRAM;
          if (!repeat) {
            Program::next();
          }
          break;
        case IR_7::DMX:
          mode = Mode::TRANCE_MODE;
          break;
        case IR_7::MANUAL:
          mode = Mode::MANUAL;
          break;

        case IR_7::RED:
          Manual::selected = Manual::RED;
          break;
        
        case IR_7::GREEN:
          Manual::selected = Manual::GREEN;
          break;
        
        case IR_7::BLUE:
          Manual::selected = Manual::BLUE;
          break;

        case IR_7::MIUNS:
          if (mode == Mode::MANUAL) {
            switch (Manual::selected) {
              case Manual::RED:
                if (Manual::red_level > 0) Manual::red_level--;
                break;
              case Manual::GREEN:
                if (Manual::green_level > 0) Manual::green_level--;
                break;
              case Manual::BLUE:
                if (Manual::blue_level > 0) Manual::blue_level--;
                break;
            }
          }
          break;

        case IR_7::PLUS:
          if (mode == Mode::MANUAL) {
            switch (Manual::selected) {
              case Manual::RED:
                if (Manual::red_level < 9) Manual::red_level++;
                break;
              case Manual::GREEN:
                if (Manual::green_level < 9) Manual::green_level++;
                break;
              case Manual::BLUE:
                if (Manual::blue_level < 9) Manual::blue_level++;
                break;
            }
          }
          break;
        
        default:
          //Serial.println("Unknown Key pressed.");
          break;
      }
    }

    IrReceiver.resume();
  }
}

void handle_modes() {

  if (mode == Mode::MANUAL) {
    CRGB color = CRGB(Manual::red_level * 28, Manual::green_level * 28, Manual::blue_level * 28);
    for (int i = 0; i < NUM_LEDS; i++) {
      leds[i] = color;
    }
  }

  if (mode == Mode::BLACK_OUT) {
    for (int i = 0; i < NUM_LEDS; i++) {
      leds[i] = CRGB::Black;
    }
  }

  if (mode == Mode::PROGRAM) {

      switch (Program::current) {
        case (Program::RAINBOW):
          for (int i = 0; i < NUM_LEDS; i++) {
            leds[i] = CHSV(i*4 + beat8(Program::animation_speed), 255, 255);
          }
          break;

        case (Program::ABSTRACT):
          for (int i = 0; i < NUM_LEDS; i++) {
            leds[i] = CHSV(beatsin8(Program::animation_speed, 140, 255, 0, i*4), 180, 255);
          }
          break;

        case (Program::FIRE):
          for (int i = 0; i < NUM_LEDS; i++) {
            leds[i] = CHSV(beatsin8(Program::animation_speed, 0, 60, 0, i*5), 250, beatsin8(Program::animation_speed, 150, 255, 0, i*7));
          }
          break;
        
        case (Program::OCEAN):
          for (int i = 0; i < NUM_LEDS; i++) {
            leds[i] = CHSV(beatsin8(Program::animation_speed, 120, 170, 0, i*2), beatsin8(Program::animation_speed, 180, 255, 0, i*2), 255);
          }
          break;
        
        case (Program::LINE):
          for (int i = 0; i < NUM_LEDS; i++) {
            leds[i] = CHSV(beat8(Program::animation_speed), 255, beatsin8(Program::animation_speed, 0, 255, 0, i*51 + beat8(Program::animation_speed)) );
          }
          break;
      }
  }

}

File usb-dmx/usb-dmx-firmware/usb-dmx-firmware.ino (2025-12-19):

/*
  Board: TRANCE USB-DMX rev: 1.2
  Board Library: esp32 v3.0.4
  Dependencies: trance v0.0.3, esp_dmx v4.1.0, ArtNet v0.9.2
  Author: Samuel Hafen
*/

#include <Arduino.h>
#include <esp_dmx.h>

#include <Trance.h>

int transmitPin = 4;
int receivePin = 1;
int enablePin = 3;

dmx_port_t dmxPort = 1;

uint8_t data[DMX_PACKET_SIZE];

// Prototype because compiler sad
void callback(uint8_t test[]);

void setup() {

  Trance.begin(512, callback, 0);

  // Setup DMX Driver
  dmx_config_t config = DMX_CONFIG_DEFAULT;
  dmx_personality_t personalities[] = {};
  int personality_count = 0;
  dmx_driver_install(dmxPort, &config, personalities, personality_count);
  dmx_set_pin(dmxPort, transmitPin, receivePin, enablePin);
}

void loop() {
  Trance.handle();

  dmx_write(dmxPort, data, DMX_PACKET_SIZE);
  dmx_send_num(dmxPort, DMX_PACKET_SIZE);
  dmx_wait_sent(dmxPort, DMX_TIMEOUT_TICK);
  delay(5);
}

// recieves data from Trance
void callback(uint8_t channels[]) {

  // Index 0 from trance is DMX channel 1
  memcpy(&data[1], channels, 512);
}

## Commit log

2025-02-15 creating concepts and prototypes
    [controller.kicad_sch, kicad.kicad_pcb, kicad.kicad_sch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]
2025-02-15 adding enclosure prototype
    [wall-adapter.FCStd]
2025-02-15 removing angle from plug
    [wall-adapter.FCStd]
2025-04-23 creating custom devboard
    [devboard.kicad_pcb, devboard.kicad_sch]
2025-04-23 connecting all remaining IOs
    [devboard.kicad_pcb, devboard.kicad_sch]
2025-04-23 adding mouser part number to all parts
    [devboard.kicad_pcb, devboard.kicad_sch]
2025-04-24 designed pcb
    [devboard.kicad_pcb, devboard.kicad_sch]
2025-04-29 changing pinout to more gnd
    [devboard.kicad_pcb, devboard.kicad_sch]
2025-05-03 removing old approaches
    [controller.kicad_sch, kicad.kicad_pcb, kicad.kicad_sch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]
2025-05-03 adding Kicad gitignore entrys
2025-05-03 adding a new pcb, on which de devboard will be used.
    [wifi-dmx.kicad_pcb, wifi-dmx.kicad_sch]
2025-05-27 adding GND vias, creating gerber files
    [devboard-B_Cu.gbr, devboard-B_Mask.gbr, devboard-B_Paste.gbr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]
2025-05-28 adding XLD connector
    [wifi-dmx.kicad_pcb, wifi-dmx.kicad_sch]
2025-05-29 adding pdf of schematic and pcb
2025-05-29 adding measurements to pcb
    [devboard.kicad_pcb]
2025-05-29 finishing schematic and organizing pcb
    [wifi-dmx.kicad_pcb, wifi-dmx.kicad_sch]
2025-05-29 removing wall adapter enclosure
    [wall-adapter.FCStd]
2025-05-29 adding project for eth-dmx configuration
    [eth-dmx.kicad_pcb, eth-dmx.kicad_sch]
2025-05-30 adding enclosure sketch
    [sketch.dxf]
2025-06-02 creating enclosure design
    [enclosure.scad, sketch.dxf]
2025-06-03 adding lid
    [enclosure.scad]
2025-06-03 adding button and led to pcb
    [wifi-dmx.kicad_pcb, wifi-dmx.kicad_sch]
2025-06-04 finishing schematic, finishing pcb, integrating pcb-stl with enclosure
    [enclosure.scad, wifi-dmx.kicad_pcb, wifi-dmx.kicad_sch]
2025-06-04 adding button and led to enclosure
    [enclosure.scad]
2025-06-04 adding board details on silkscreen
    [wifi-dmx.kicad_pcb]
2025-06-04 hiding mouser part numbers in schematic
    [wifi-dmx.kicad_sch]
2025-06-07 adding SMA hole
    [enclosure.scad]
2025-06-07 adding clip mount
    [enclosure.scad]
2025-07-02 creating schematic for eurolite led 7c-7 retrofit
    [eurolite-led-7c-7.kicad_pcb, eurolite-led-7c-7.kicad_sch]
2025-07-02 adding current project status
    [eurolite-led-7c-7.kicad_pcb]
2025-07-02 adding cover
    [cover-Body.3mf, cover.FCStd]
2025-07-02 creating schematic for usb-dmx
    [usb-dmx.kicad_pcb, usb-dmx.kicad_sch]
2025-07-03 creating pcb for usb-dmx
    [usb-dmx.kicad_pcb]
2025-07-08 adding receiving voltage divider and renaming components
    [usb-dmx.kicad_pcb, usb-dmx.kicad_sch]
2025-07-14 preparing usb-dmx for production
    [usb-dmx-B_Cu.gbr, usb-dmx-B_Mask.gbr, usb-dmx-B_Paste.gbr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]
2025-07-14 removing modding attempt
    [eurolite-led-7c-7.kicad_pcb, eurolite-led-7c-7.kicad_sch]
2025-07-14 reorganizing repo, removing stale projects
    [cover-Body.3mf, cover.FCStd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]
2025-07-14 adding external antenna to schematic
    [usb-dmx.kicad_pcb, usb-dmx.kicad_sch]
2025-08-13 Adding other Voltage Regulator
    [usb-dmx.kicad_pcb, usb-dmx.kicad_sch]
2025-08-29 adding new device
2025-09-06 fixing pcb, reorganizing firmware library
    [usb-dmx-B_Cu.gbr, usb-dmx-B_Mask.gbr, usb-dmx-B_Paste.gbr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]
2025-09-30 updating gerber files
    [usb-dmx-B_Cu.gbr, usb-dmx-B_Mask.gbr, usb-dmx-B_Paste.gbr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]
2025-10-02 adding dmx output, removing pwm outputs
2025-10-03 cleaning up repository
    [usb-dmx-B_Cu.gbr, usb-dmx-B_Mask.gbr, usb-dmx-B_Paste.gbr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]
2025-10-03 adding larger capacitor to esp and exchanging parts
    [usb-dmx.kicad_pcb, usb-dmx.kicad_sch]
2025-10-06 fingind aliexpress alternatives
    [usb-dmx.kicad_pcb, usb-dmx.kicad_sch]
2025-10-07 creating pcb layout
    [usb-dmx-B_Cu.gbr, usb-dmx-B_Mask.gbr, usb-dmx-B_Paste.gbr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]
2025-12-22 changing to 2 part housing
    [housing.3mf, housing.FCStd]
2025-12-22 creating rough design
    [pixel-led.kicad_pcb, pixel-led.kicad_sch]
2026-01-12 moved sketch, used usb-dmx as template
    [pixel-led.kicad_pcb, pixel-led.kicad_sch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]
2026-01-13 finishing layout
    [pixel-led.kicad_pcb, pixel-led.kicad_sch]
2026-01-21 creating gerber
    [pixel-led-B_Cu.gbr, pixel-led-B_Mask.gbr, pixel-led-B_Paste.gbr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]
2026-01-22 adding ir-remote for led-strip
2026-01-22 reworking animation system, for smooth speed change
    [remote.h]
2026-02-07 changing data Pin
